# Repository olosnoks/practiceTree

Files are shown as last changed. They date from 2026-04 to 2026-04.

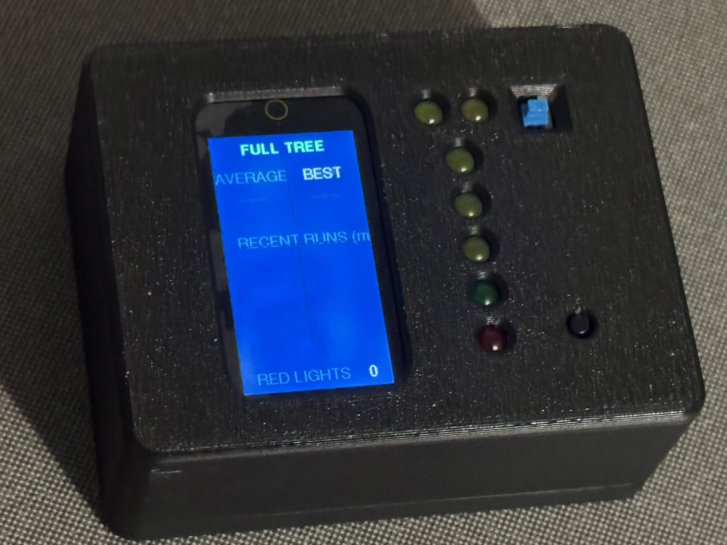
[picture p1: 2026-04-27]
hardware/3d/3d_printed_enclosure.jpg

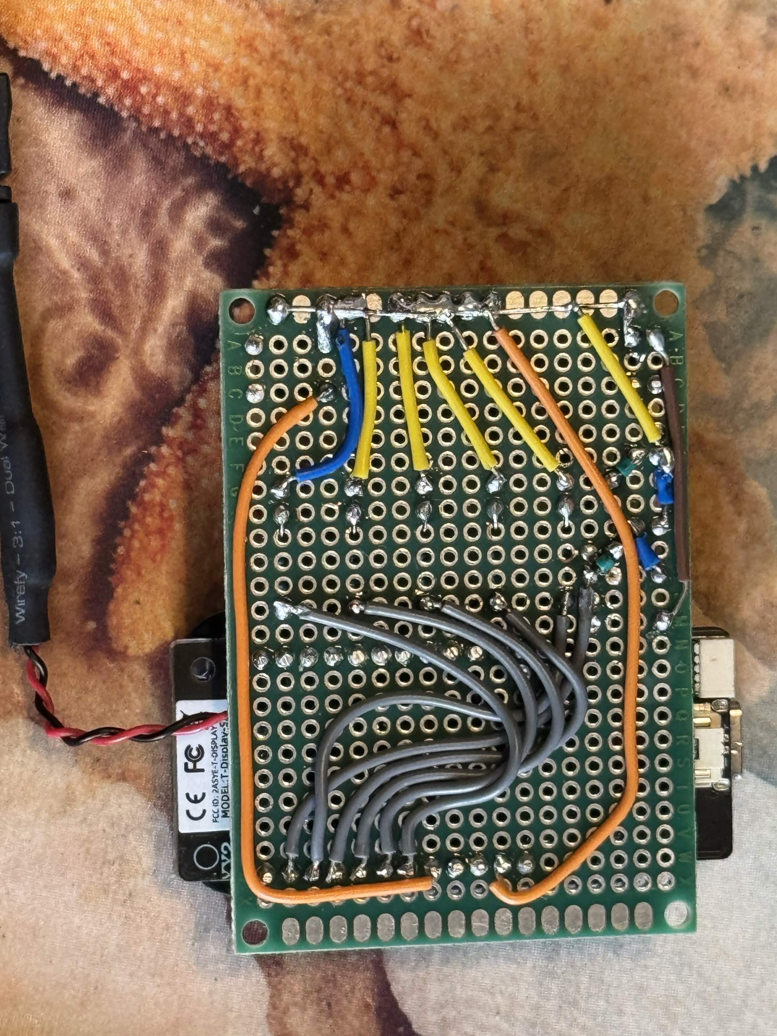
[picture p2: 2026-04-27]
hardware/3d/board_assembly_back.jpg

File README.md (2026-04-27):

# 🚦 Practice Tree — Reaction Timer for T-Display S3

A drag racing Christmas tree reaction timer built on the **LILYGO T-Display S3**, using an external LED tree and a single push button. Simulates a full NHRA-style countdown sequence and measures your reaction time to the nearest millisecond.

---

## ✨ Features

- 🌲 **Full Tree mode** — sequential yellow lights, 500ms between each
- ⚡ **Pro Tree mode** — sequential yellow lights, 100ms between each (triple-tap to switch)
- 🎲 **Random stage delay** — 1–7 second random hold after staging before the tree drops
- ⏱️ **Reaction time measurement** — millisecond-accurate, displayed in `.XXX` second format
- 🏆 **Personal best tracking** — best RT persists across all runs in the session, highlighted in blue
- 📊 **Rolling history** — last 12 reaction times displayed in a 2×6 grid
- 🔴 **Red light detection** — releasing before green increments the red light counter
- 💡 **Pre-stage debounce** — button must be held 500ms before staging LED fires (prevents accidental triggers)
- 🖥️ **Sprite-buffered display** — flicker-free rendering via LGFX double-buffering

---

## 🛠️ Bill of Materials

### Electronics

| Qty | Component | Specs | Notes |
|-----|---|---|---|
| 1 | LILYGO T-Display S3 | ESP32-S3, 1.9" ST7789 LCD | Main controller with integrated display |
| 1 | Perfboard | 5×7cm | LED tree assembly |
| 7 | Resistors | 680Ω, 1/4W | Current limiting — one per LED |
| 5 | Yellow LEDs | 5mm | Stage + tree countdown sequence |
| 1 | Green LED | 5mm | Go light |
| 1 | Red LED | 5mm | Red light / foul indicator |
| 1 | Push button | Momentary SPST | Trigger, wired to GPIO13 |
| 1 | Power switch | DPDT latching (6-pin) | Reset bypass for hard power-off |
| 1 | LiPo battery | 3.7V 2000mAh with JST connector | Portable power source |

### Hardware

| Qty | Size | Purpose |
|-----|---|---|
| 4 | 2mm × 8mm machine screws | Perfboard / component mounting |
| 4 | 2mm × 12mm machine screws | Enclosure assembly |

---

## 🔌 Wiring

### Pin Map

| GPIO | Connected To | Notes |
|---|---|---|
| `1`  | Stage LED + 680Ω resistor | Staging indicator |
| `2`  | Yellow 1 LED + 680Ω resistor | First yellow |
| `3`  | Yellow 2 LED + 680Ω resistor | Second yellow |
| `10` | Yellow 3 LED + 680Ω resistor | Third yellow |
| `11` | Green LED + 680Ω resistor | Go light |
| `12` | Red LED + 680Ω resistor | Red light / foul |
| `13` | Push button (to GND) | `INPUT_PULLUP` — reads LOW when pressed |
| `15` | Display power enable | Driven `HIGH` on boot to power the display |

### Button Wiring

The button uses the ESP32's internal pull-up — no external resistor needed:

```
GPIO 13 ───────────── Button ───────────── GND
              (INPUT_PULLUP)
```

### LED Wiring (per LED)

```
GPIO ──── [680Ω] ──── LED (+) ──── GND
```

### Power Switch — Reset Bypass

The DPDT latching switch forces an off state by shorting the RST signal pad on the reset button to GND:

```
RST signal pad ───── [Switch] ───── GND
```

When latched closed, the RST line is held LOW and the board stays in reset (off). Open the switch and the board boots normally.

**To wire:**
1. Solder a wire to the RST signal pad on the T-Display S3 reset button
2. Solder a wire to any GND pad or pin
3. Run both to your DPDT latching switch

### Schematic Overview

```
T-Display S3
┌────────────────┐
│ GPIO 1  ───────┼── 680Ω ── [STAGE  LED] ── GND
│ GPIO 2  ───────┼── 680Ω ── [YELLOW 1  ] ── GND
│ GPIO 3  ───────┼── 680Ω ── [YELLOW 2  ] ── GND
│ GPIO 10 ───────┼── 680Ω ── [YELLOW 3  ] ── GND
│ GPIO 11 ───────┼── 680Ω ── [GREEN  LED] ── GND
│ GPIO 12 ───────┼── 680Ω ── [RED    LED] ── GND
│ GPIO 13 ───────┼──────────── [BTN] ──── GND
│ GPIO 15 ───────┼── Display power enable
│ BAT+    ───────┼── LiPo (+) 3.7V JST
│ GND     ───────┼── LiPo (-)
│ RST Pad ───────┼── [Power Switch] ──── GND
└────────────────┘
```

---

## 🖥️ Display Screens

### Idle / History Screen

```
┌─────────────────────┐
│      FULL TREE      │  ← header (switches to PRO TREE)
├──────────┬──────────┤
│ AVERAGE  │  BEST    │
│  .412    │  .308    │  ← .XXX format; best in blue
├──────────┴──────────┤
│  RECENT RUNS (ms)   │
│  .412  │  .389      │
│  .455  │  .308      │  ← 2×6 grid, 12 entries max
│  ...   │  ...       │  ← best time highlighted in blue
├─────────────────────┤
│ RED LIGHTS        2 │  ← pinned to bottom
└─────────────────────┘
```

### Staging Screen

```
┌─────────────────────┐
│      FULL TREE      │
│                     │
│      STAGING        │
│  Hold the button... │
└─────────────────────┘
```

### Result Screen — Good Run

```
┌─────────────────────┐
│   REACTION TIME     │
│                     │
│       .412          │
│                     │
│   press for history │
└─────────────────────┘
```

### Result Screen — Red Light

```
┌─────────────────────┐
│                     │
│        RED          │
│       LIGHT         │
│   Press to reset    │
└─────────────────────┘
```

---

## 🕹️ Usage

### Basic Run

1. **Hold** the button — after 500ms the **stage LED** lights up
2. **Keep holding** — after a random 1–7s delay the yellow sequence fires
3. **Release** as fast as possible when the **green light** comes on
4. Your reaction time is displayed in `.XXX` format
5. **Press** again to return to the history screen

### Red Light

- Releasing **before green** fires the red LED and increments the counter
- Press the button to reset to idle

### Mode Switching — Triple Tap

Tap the button **3 times** quickly (each tap < 500ms hold, all 3 within a 1500ms window) to toggle between Full Tree and Pro Tree.

| Mode | Yellow Behavior | Timing |
|---|---|---|
| **Full Tree**| 500ms per step |
| **Pro Tree** | 100ms to green |

The active mode is shown in the header on every screen.

---

## 🛠️ Build & Flash

### Project Structure

```
practiceTree/
├── platformio.ini
├── src/
│   ├── main.cpp
│   └── LGFX_TDisplayS3.h
├── .gitignore
└── .gitattributes
```

### platformio.ini

```ini
[env:esp32s3]
platform      = espressif32
board         = esp32-s3-devkitc-1
framework     = arduino
monitor_speed = 115200
upload_speed  = 921600
lib_deps      =
    lovyanGFX
build_flags   =
    -D LGFX_USE_V1
```

### Arduino IDE

1. Install **ESP32 board package** via Boards Manager
2. Install **LovyanGFX** via Library Manager
3. Select board: **LILYGO T-Display-S3**
4. Copy both `src/main.cpp` and `src/LGFX_TDisplayS3.h` into the same sketch folder
5. Upload

---

## ⚙️ Configurable Constants

All tunable values are at the top of `src/main.cpp`:

| Constant | Default | Description |
|---|---|---|
| `PRE_STAGE_MS` | `500` | Hold time before staging LED fires (ms) |
| `STAGE_DELAY_MS` | `1000–7000` | Randomized delay before tree drops (ms) |
| `STEP_DELAY_MS` | `500` / `100` | Full tree step delay / Pro tree delay to green (ms) |
| `TAP_WINDOW_MS` | `1500` | Time window for triple-tap mode switch (ms) |
| `HISTORY_SIZE` | `12` | Number of previous runs stored and displayed |

---

## 📐 State Machine

```
         [hold 500ms]           [random 1–7s]
  IDLE ──────────────▶ PRE_STAGE ────────────▶ STAGING
   ▲                      │                      │
   │                 [release]             [delay elapsed]
   │                 (tap counted)               │
   │                      ▼              ┌───────┴────────┐
   │                    IDLE         Full Tree        Pro Tree
   │                                    │                │
   │                                  Y1_ON         PRO_YELLOW
   │                                    │ 500ms      (all 3 on)
   │                                  Y2_ON              │ 100ms
   │                                    │ 500ms           │
   │                                  Y3_ON               │
   │                                    │ 500ms           │
   │                                    └────────┬────────┘
   │                                             ▼
   │                                       GREEN_ON_HELD
   │                                             │
   │                    [release before green]   │   [release after green]
   │                             │               │
   │                          RED_END        GREEN_END
   │                             │               │
   └──────────[press]────────────┴───────────────┘
```

---

## 📄 License

MIT — do whatever you want with it. Build one for your buddy's Christmas present.

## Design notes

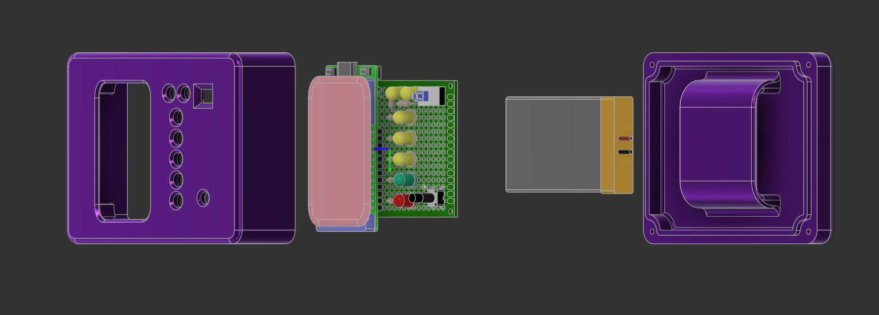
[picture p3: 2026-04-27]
hardware/3d/cad_render.png

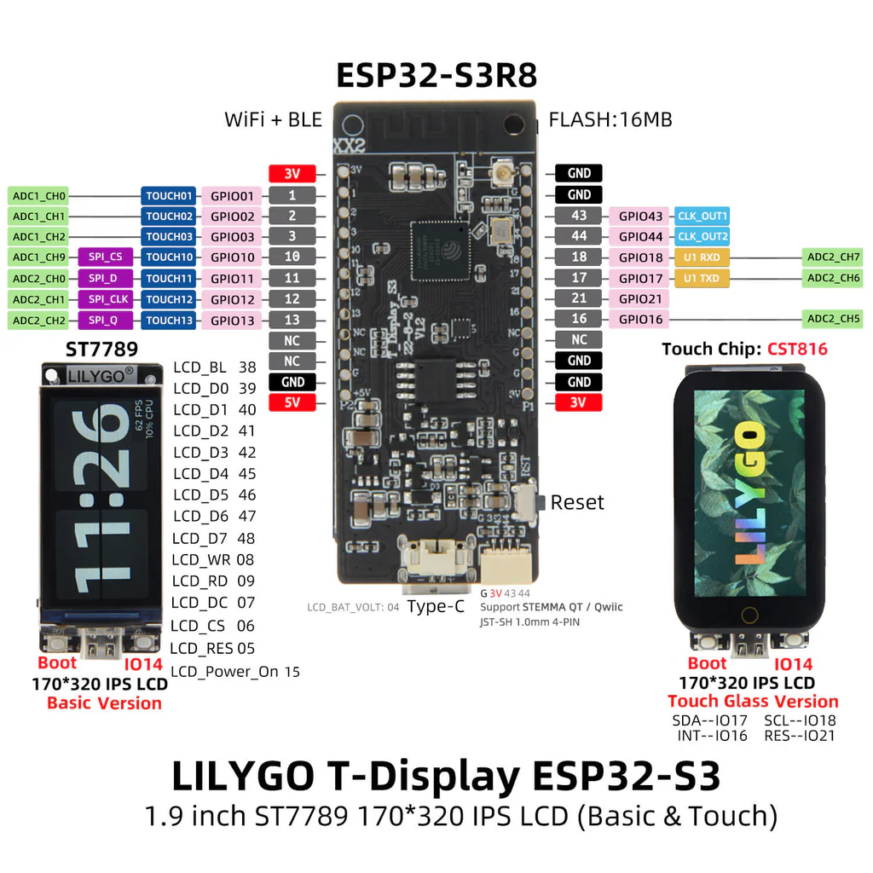
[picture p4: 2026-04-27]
hardware/T-DISPLAY-S3-Touch_1024x1024.webp

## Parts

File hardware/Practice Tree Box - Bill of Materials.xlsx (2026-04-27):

# | Item | Description / Notes | Category | Qty | Unit | Amazon Link
1 | LilyGo T-Display S3 | ESP32-S3 dev board with 1.9" TFT display, USB-C, onboard LiPo charging IC, JST battery connector | Microcontroller | 1 | pcs | LilyGo T-Display S3 (https://www.amazon.com/dp/B0BF542H39)
2 | 3.7V 2000mAh LiPo Battery | With JST-PH 2.0 connector, rechargeable via onboard LilyGo charging IC | Power | 1 | pcs | EEMB 3.7V 2000mAh LiPo JST (https://www.amazon.com/dp/B09DPP44GM)
3 | 6-Pin DPDT Latching Tactile Switch | Push-on/push-off PCB mount switch, 3 legs per side; wired to RST pad and GND on LilyGo to force hardware OFF state while allowing charging | Power | 1 | pcs | Antrader 30pc 6-Pin DPDT Latching Switch (https://www.amazon.com/dp/B07QVX1CKZ)
4 | Yellow 5mm LED | Used for tree light sequence (staging lights) | LEDs | 5 | pcs | DiCUNO 450pc 5mm LED Assorted Kit (https://www.amazon.com/dp/B073QMYKDM)
5 | Red 5mm LED | Used for tree light sequence (Red-Light indicator) | LEDs | 1 | pcs | DiCUNO 450pc 5mm LED Assorted Kit
6 | Green 5mm LED | Used for tree light sequence (GO light) | LEDs | 1 | pcs | DiCUNO 450pc 5mm LED Assorted Kit
7 | 680 Ohm 1/4W Resistor | Current limiting resistors for all 7 LEDs (5x Yellow + 1x Red + 1x Green), one per LED | Passives | 7 | pcs | 100pc 680 Ohm 1/4W Carbon Film Resistors (https://www.amazon.com/dp/B0CL9LX4R3)
8 | 5x7cm Perfboard | Prototype PCB for soldering all components | Mechanical | 1 | pcs | HiLetgo 20pc 5x7cm Perfboard (https://www.amazon.com/dp/B00FXHXT80)
9 | M2x8mm Screw | For mounting PCB to 3D printed Front | Hardware | 4 | pcs | 1260pc M2 Screw Assortment Kit (4-20mm) (https://www.amazon.com/dp/B0FG2CC91J)
10 | M2x12mm Screw | For mounting 3D printed Back to Front | Hardware | 4 | pcs | 1260pc M2 Screw Assortment Kit (4-20mm)
11 | Hookup Wire (assorted) | Thin stranded wire for point-to-point wiring on perfboard and switch connections | Wiring | 1 | roll | TUOFENG 22AWG Hookup Wire 6 Colors (https://www.amazon.com/dp/B07TX6BX47)
13 | 6x6x12mm Momentary Tactile Pushbutton | 4-pin PCB DIP through-hole, normally open, tall stem; used to trigger the practice tree light sequence | Switches | 1 | pcs | uxcell 6x6x12mm 4-Pin DIP Tactile Switch 10pcs (https://www.amazon.com/dp/B07JLV6WSF)

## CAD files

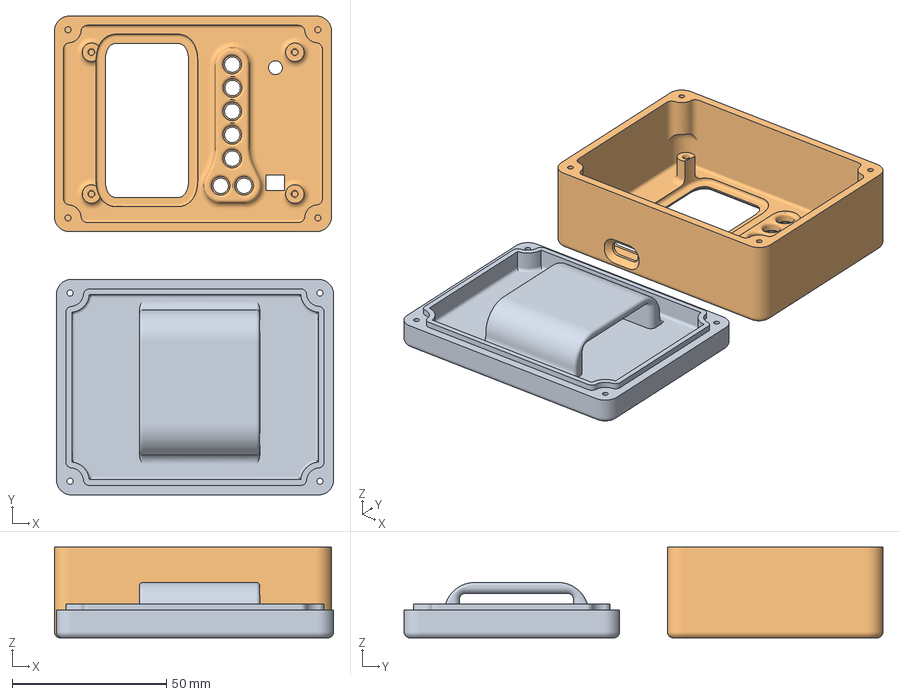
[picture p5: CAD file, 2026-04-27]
hardware/3d/DIY_Practice_Tree.3mf
90.7 x 155.4 x 29.5 mm
back
front

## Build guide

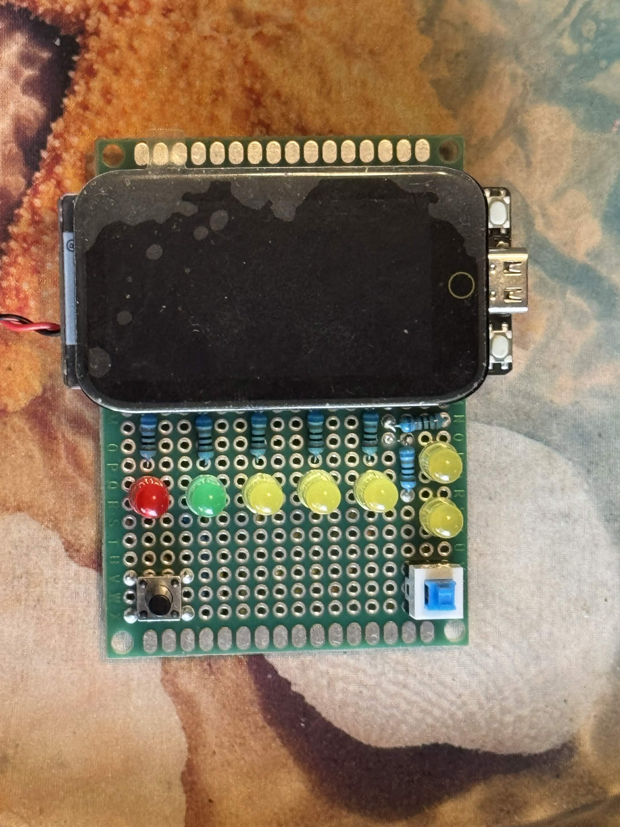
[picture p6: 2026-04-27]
hardware/3d/board_assembly.jpg

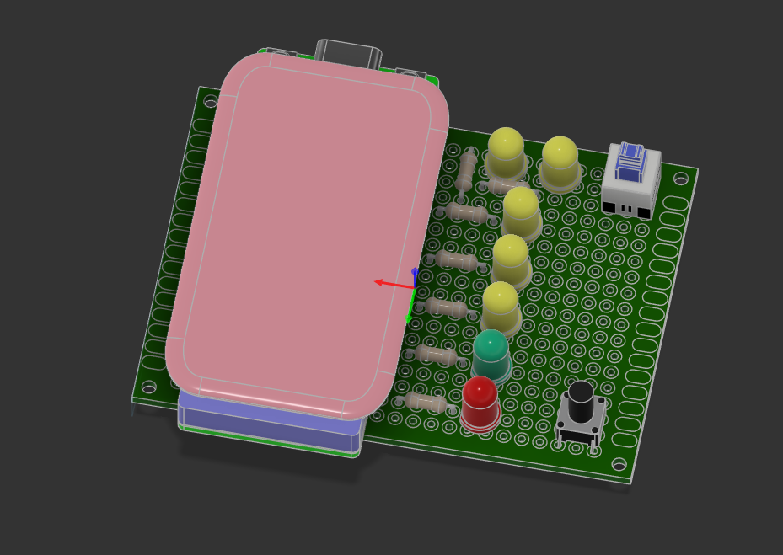
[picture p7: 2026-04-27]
hardware/3d/board_assembly.png

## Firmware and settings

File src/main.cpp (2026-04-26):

#include <Arduino.h>
#define LGFX_USE_V1
#include "LGFX_TDisplayS3.h"


// ── Display ───────────────────────────────────────────────────────
static LGFX_TDisplayS3 lcd;
static LGFX_Sprite      spr(&lcd);
constexpr int DISPLAY_POWER_PIN = 15;
int  redLightCount = 0;
bool proTreeMode   = false;


// Tap detection for mode switching
int           tapCount    = 0;
unsigned long lastTapTime = 0;
const unsigned long TAP_WINDOW_MS    = 1500;
const unsigned long PRE_STAGE_MS     = 500;


unsigned long tachStartTime = 0;
bool tachAnimating = false;


// =================================================================
// GAME CODE
// =================================================================


const int PIN_STAGE = 1;
const int PIN_Y1    = 2;
const int PIN_Y2    = 3;
const int PIN_Y3    = 10;
const int PIN_GREEN = 11;
const int PIN_RED   = 12;
const int PIN_BTN   = 13;


enum TreeState {
  IDLE,
  PRE_STAGE,
  STAGING,
  Y1_ON,
  Y2_ON,
  Y3_ON,
  PRO_YELLOW,
  GREEN_ON_HELD,
  RED_END,
  GREEN_END
};


TreeState state = IDLE;


unsigned long stateStartTime = 0;
unsigned long STAGE_DELAY_MS = 2000;
unsigned long STEP_DELAY_MS  = 500;


unsigned long greenOnTimeMs  = 0;
unsigned long lastReactionMs = 0;
unsigned long bestReactionMs = 0;   // best (lowest) reaction time ever recorded


const int HISTORY_SIZE = 12;
unsigned long reactionHistory[HISTORY_SIZE] = {0};
int historyCount = 0;


bool buttonPressed() {
  return digitalRead(PIN_BTN) == LOW;
}


void allOff() {
  digitalWrite(PIN_STAGE, LOW);
  digitalWrite(PIN_Y1, LOW);
  digitalWrite(PIN_Y2, LOW);
  digitalWrite(PIN_Y3, LOW);
  digitalWrite(PIN_GREEN, LOW);
  digitalWrite(PIN_RED, LOW);
}


void addReactionToHistory(unsigned long rt) {
  for (int i = HISTORY_SIZE - 1; i > 0; --i) {
    reactionHistory[i] = reactionHistory[i - 1];
  }
  reactionHistory[0] = rt;
  if (historyCount < HISTORY_SIZE) historyCount++;

  if (bestReactionMs == 0 || rt < bestReactionMs) {
    bestReactionMs = rt;
  }
}


float averageReaction() {
  if (historyCount == 0) return 0.0f;
  unsigned long sum = 0;
  for (int i = 0; i < historyCount; ++i) sum += reactionHistory[i];
  return (float)sum / (float)historyCount;
}



// Format reaction time as ".XXX" (sub-second) or "1.XXX" (1s+)
void formatRT(char* buf, int bufSize, unsigned long ms) {
  snprintf(buf, bufSize, "%.3f", ms / 1000.0f);
  if (buf[0] == '0') memmove(buf, buf + 1, strlen(buf)); // strip leading zero
}

// =================================================================
// DISPLAY LAYER
// =================================================================


void drawHeader() {
  const int W = spr.width();
  spr.fillRect(0, 0, W, 36, 0x1A1A1A);
  spr.setTextDatum(MC_DATUM);
  spr.setFont(&fonts::FreeSansBold9pt7b);
  spr.setTextSize(1);
  spr.setTextColor(0x4CAF50);
  spr.drawString(proTreeMode ? "PRO TREE" : "FULL TREE", W / 2, 18);
}


void drawDisplay() {
  const int W = spr.width();
  const int H = spr.height();

  spr.fillSprite(0x0A0A0A);
  char buf[16];


  if (state == GREEN_END) {

    drawHeader();
    spr.setTextDatum(MC_DATUM);
    spr.setFont(&fonts::FreeSans9pt7b);
    spr.setTextColor(0x666666);
    spr.drawString("REACTION TIME", W / 2, 80);

    spr.setFont(&fonts::FreeSansBold9pt7b);
    spr.setTextSize(2);
    spr.setTextColor(TFT_WHITE);
    formatRT(buf, sizeof(buf), lastReactionMs);
    spr.drawString(buf, W / 2, 120);


    spr.setTextColor(0x333333);
    spr.drawString("press for history", W / 2, H - 20);


  } else if (state == IDLE || state == PRE_STAGE) {

    drawHeader();

    // ── Stats row: AVG (left) + BEST (right) ──────────────────────
    const int colL = W / 4;
    const int colR = (W * 3) / 4;

    const int statsLabelY = 54;
    const int statsValueY = 82;

    spr.setFont(&fonts::FreeSans9pt7b);
    spr.setTextSize(1);
    spr.setTextDatum(MC_DATUM);

    spr.setTextColor(0x555555);
    spr.drawString("AVERAGE", colL, statsLabelY);
    spr.setTextColor(TFT_WHITE);
    spr.drawString("BEST", colR, statsLabelY);

    spr.setFont(&fonts::FreeSansBold9pt7b);
    spr.setTextSize(2);

    if (historyCount > 0) {
      spr.setTextColor(TFT_WHITE);
      formatRT(buf, sizeof(buf), (unsigned long)averageReaction());
    } else {
      spr.setTextColor(0x333333);
      snprintf(buf, sizeof(buf), "---");
    }
    spr.drawString(buf, colL, statsValueY);

    if (bestReactionMs > 0) {
      spr.setTextColor(TFT_WHITE);
      formatRT(buf, sizeof(buf), bestReactionMs);
    } else {
      spr.setTextColor(0x333333);
      snprintf(buf, sizeof(buf), "---");
    }
    spr.drawString(buf, colR, statsValueY);

    spr.setTextSize(1);
    spr.setFont(&fonts::FreeSans9pt7b);

    spr.drawFastVLine(W / 2, 48, 68, 0x222222);

    // ── Footer pinned to bottom ────────────────────────────────────
    const int footerLineY = H - 34;
    const int footerTextY = H - 24;

    spr.drawFastHLine(16, footerLineY, W - 32, 0x2A2A2A);
    spr.setTextDatum(TL_DATUM);
    spr.setTextColor(0x555555);
    spr.setFont(&fonts::FreeSans9pt7b);
    spr.drawString("RED LIGHTS", 16, footerTextY);
    spr.setTextDatum(TR_DATUM);
    spr.setTextColor(TFT_WHITE);
    snprintf(buf, sizeof(buf), "%d", redLightCount);
    spr.drawString(buf, W - 16, footerTextY);

    // ── Recent runs section (2x5 grid) ────────────────────────────
    const int recentTitleY = 128;
    const int recentLineY  = 140;
    const int rowY0        = 154;
    const int rowH         = 18;

    spr.drawFastHLine(16, recentTitleY - 8, W - 32, 0x2A2A2A);
    spr.setTextColor(0x555555);
    spr.setTextDatum(TL_DATUM);
    spr.drawString("RECENT RUNS (ms)", 16, recentTitleY);
    spr.drawFastHLine(16, recentLineY, W - 32, 0x222222);

    int count = min(historyCount, HISTORY_SIZE);
    for (int i = 0; i < count; i++) {
      int  row     = i / 2;
      bool leftCol = (i % 2 == 0);
      int x = leftCol ? colL : colR;
      int y = rowY0 + row * rowH;

      formatRT(buf, sizeof(buf), reactionHistory[i]);
      spr.setTextColor(reactionHistory[i] == bestReactionMs ? (uint32_t)0x6699CC : (uint32_t)TFT_WHITE);
      spr.setTextDatum(MC_DATUM);
      spr.drawString(buf, x, y);
    }

    int historyHeight = footerLineY - rowY0 - 4;
    if (historyHeight > 0) {
      spr.drawFastVLine(W / 2, recentLineY, historyHeight, 0x222222);
    }


  } else if (state == RED_END) {

    spr.setTextDatum(MC_DATUM);
    spr.setTextColor(TFT_RED);
    spr.setTextSize(2);
    spr.setFont(&fonts::FreeSansBold9pt7b);
    spr.drawString("RED", W / 2, H / 2 - 24);
    spr.drawString("LIGHT", W / 2, H / 2 + 4);
    spr.setTextSize(1);
    spr.setTextColor(0x555555);
    spr.setFont(&fonts::FreeSans9pt7b);
    spr.drawString("Press to reset", W / 2, H / 2 + 46);


  } else {

    // STAGING, Y1_ON, Y2_ON, Y3_ON, PRO_YELLOW, GREEN_ON_HELD
    drawHeader();
    spr.setTextDatum(MC_DATUM);
    spr.setTextColor(0xFFCC00);
    spr.setTextSize(2);
    spr.setFont(&fonts::FreeSansBold9pt7b);
    spr.drawString("STAGING", W / 2, H / 2 - 14);
    spr.setTextSize(1);
    spr.setTextColor(0x444444);
    spr.setFont(&fonts::FreeSans9pt7b);
    spr.drawString("Hold the button...", W / 2, H / 2 + 22);

  }

  spr.pushSprite(0, 0);
}


// =================================================================
// SETUP & LOOP
// =================================================================


void setup() {
  pinMode(DISPLAY_POWER_PIN, OUTPUT);
  digitalWrite(DISPLAY_POWER_PIN, HIGH);
  delay(10);

  lcd.init();
  lcd.setRotation(2);
  lcd.setBrightness(200);
  spr.setColorDepth(16);
  spr.createSprite(lcd.width(), lcd.height());

  Serial.begin(115200);
  delay(500);

  pinMode(PIN_STAGE, OUTPUT);
  pinMode(PIN_Y1,    OUTPUT);
  pinMode(PIN_Y2,    OUTPUT);
  pinMode(PIN_Y3,    OUTPUT);
  pinMode(PIN_GREEN, OUTPUT);
  pinMode(PIN_RED,   OUTPUT);
  pinMode(PIN_BTN,   INPUT_PULLUP);

  allOff();
  drawDisplay();

  Serial.println("=== Drag tree with reaction time ===");
  Serial.println("Release BEFORE green -> red only.");
  Serial.println("Release AFTER green -> green only + reaction time.");
}


void loop() {
  unsigned long now = millis();
  bool pressed = buttonPressed();

  TreeState prevState = state;

  switch (state) {

    case IDLE:
      allOff();
      if (pressed) {
        Serial.println("[IDLE] -> PRE_STAGE");
        stateStartTime = now;
        state = PRE_STAGE;
      }
      break;

    case PRE_STAGE:
      if (!pressed) {
        Serial.println("[PRE_STAGE] Released quickly -> IDLE (tap)");
        state = IDLE;
        break;
      }
      if (now - stateStartTime >= PRE_STAGE_MS) {
        Serial.println("[PRE_STAGE] 500ms held -> STAGING");
        STAGE_DELAY_MS = random(1000, 7001);
        Serial.print("[PRE_STAGE] Stage delay = ");
        Serial.print(STAGE_DELAY_MS);
        Serial.println(" ms");
        digitalWrite(PIN_STAGE, HIGH);
        stateStartTime = now;
        state = STAGING;
      }
      break;

    case STAGING:
      digitalWrite(PIN_STAGE, HIGH);
      if (!pressed) {
        Serial.println("[STAGING] Released early -> IDLE");
        state = IDLE;
        break;
      }
      if (now - stateStartTime >= STAGE_DELAY_MS) {
        Serial.println("[STAGING] delay elapsed -> Y1_ON");
        digitalWrite(PIN_Y1, HIGH);
        stateStartTime = now;
        state = Y1_ON;
      }
      break;

    case PRO_YELLOW:
      digitalWrite(PIN_STAGE, HIGH);
      digitalWrite(PIN_Y1, HIGH);
      digitalWrite(PIN_Y2, HIGH);
      digitalWrite(PIN_Y3, HIGH);
      if (!pressed) {
        Serial.println("[PRO_YELLOW] Released early -> RED_END");
        allOff();
        digitalWrite(PIN_RED, HIGH);
        state = RED_END;
        break;
      }
      if (now - stateStartTime >= STEP_DELAY_MS) {
        Serial.println("[PRO_YELLOW] 400ms elapsed -> GREEN_ON_HELD");
        digitalWrite(PIN_GREEN, HIGH);
        greenOnTimeMs = now;
        state = GREEN_ON_HELD;
      }
      break;

    case Y1_ON:
      digitalWrite(PIN_STAGE, HIGH);
      digitalWrite(PIN_Y1, HIGH);
      if (!pressed) {
        Serial.println("[Y1_ON] Released -> RED_END");
        allOff();
        digitalWrite(PIN_RED, HIGH);
        state = RED_END;
        break;
      }
      if (now - stateStartTime >= STEP_DELAY_MS) {
        Serial.println("[Y1_ON] elapsed -> Y2_ON");
        digitalWrite(PIN_Y2, HIGH);
        stateStartTime = now;
        state = Y2_ON;
      }
      break;

    case Y2_ON:
      digitalWrite(PIN_STAGE, HIGH);
      digitalWrite(PIN_Y1, HIGH);
      digitalWrite(PIN_Y2, HIGH);
      if (!pressed) {
        Serial.println("[Y2_ON] Released -> RED_END");
        allOff();
        digitalWrite(PIN_RED, HIGH);
        state = RED_END;
        break;
      }
      if (now - stateStartTime >= STEP_DELAY_MS) {
        Serial.println("[Y2_ON] elapsed -> Y3_ON");
        digitalWrite(PIN_Y3, HIGH);
        stateStartTime = now;
        state = Y3_ON;
      }
      break;

    case Y3_ON:
      digitalWrite(PIN_STAGE, HIGH);
      digitalWrite(PIN_Y1, HIGH);
      digitalWrite(PIN_Y2, HIGH);
      digitalWrite(PIN_Y3, HIGH);
      if (!pressed) {
        Serial.println("[Y3_ON] Released -> RED_END");
        allOff();
        digitalWrite(PIN_RED, HIGH);
        state = RED_END;
        break;
      }
      if (now - stateStartTime >= STEP_DELAY_MS) {
        Serial.println("[Y3_ON] elapsed -> GREEN_ON_HELD");
        digitalWrite(PIN_GREEN, HIGH);
        greenOnTimeMs = now;
        state = GREEN_ON_HELD;
      }
      break;

    case GREEN_ON_HELD:
      digitalWrite(PIN_STAGE, HIGH);
      digitalWrite(PIN_Y1,    HIGH);
      digitalWrite(PIN_Y2,    HIGH);
      digitalWrite(PIN_Y3,    HIGH);
      digitalWrite(PIN_GREEN, HIGH);
      if (!pressed) {
        unsigned long releaseTime = now;
        lastReactionMs = releaseTime - greenOnTimeMs;
        addReactionToHistory(lastReactionMs);
        Serial.print("[GREEN_ON_HELD] Good hit, reaction = ");
        Serial.print(lastReactionMs);
        Serial.print(" ms, avg = ");
        Serial.print(averageReaction());
        Serial.print(" ms, best = ");
        Serial.print(bestReactionMs);
        Serial.println(" ms");
        allOff();
        digitalWrite(PIN_GREEN, HIGH);
        state = GREEN_END;
      }
      break;

    case RED_END:
      if (pressed) {
        Serial.println("[RED_END] Reset -> IDLE");
        state = IDLE;
      }
      break;

    case GREEN_END:
      if (pressed) {
        Serial.println("[GREEN_END] Reset -> IDLE");
        state = IDLE;
      }
      break;
  }


  // ── State change hook (display layer only) ────────────────────────
  if (state != prevState) {

    if (prevState == PRE_STAGE && state == IDLE) {
      if (now - lastTapTime < TAP_WINDOW_MS) {
        tapCount++;
      } else {
        tapCount = 1;
      }
      lastTapTime = now;

      if (tapCount >= 3) {
        proTreeMode   = !proTreeMode;
        STEP_DELAY_MS = proTreeMode ? 100 : 500;
        tapCount      = 0;
        Serial.print("[MODE] Switched to ");
        Serial.println(proTreeMode ? "PRO TREE (400ms simultaneous)" : "FULL TREE (500ms sequence)");
      }
    }

    if (state == GREEN_END || state == RED_END) tapCount = 0;
    if (state == RED_END) redLightCount++;

    // Skip no-op redraw on IDLE -> PRE_STAGE (display is identical to IDLE)
    if (!(prevState == IDLE && state == PRE_STAGE)) {
      drawDisplay();
    }
  }

  delay(1);
}

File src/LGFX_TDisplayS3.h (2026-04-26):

#pragma once
#define LGFX_USE_V1
#include <LovyanGFX.hpp>

class LGFX_TDisplayS3 : public lgfx::LGFX_Device {
  lgfx::Bus_Parallel8 _bus_instance;
  lgfx::Panel_ST7789  _panel_instance;
  lgfx::Light_PWM     _light_instance;

public:
  LGFX_TDisplayS3(void) {
    // --- 8-bit parallel bus config ---
    {
      auto cfg = _bus_instance.config();
      cfg.port          = 0;
      cfg.freq_write    = 20000000;
      cfg.pin_wr        = 8;
      cfg.pin_rd        = 9;
      cfg.pin_rs        = 7;   // D/C
      cfg.pin_d0        = 39;
      cfg.pin_d1        = 40;
      cfg.pin_d2        = 41;
      cfg.pin_d3        = 42;
      cfg.pin_d4        = 45;
      cfg.pin_d5        = 46;
      cfg.pin_d6        = 47;
      cfg.pin_d7        = 48;
      _bus_instance.config(cfg);
      _panel_instance.setBus(&_bus_instance);
    }

    // --- Panel config ---
    {
      auto cfg = _panel_instance.config();
      cfg.pin_cs        = 6;
      cfg.pin_rst       = 5;
      cfg.pin_busy      = -1;
      cfg.panel_width   = 170;
      cfg.panel_height  = 320;
      cfg.offset_x      = 35;
      cfg.offset_y      = 0;
      cfg.offset_rotation = 0;
      cfg.dummy_read_pixel = 8;
      cfg.dummy_read_bits  = 1;
      cfg.readable      = false;
      cfg.invert        = true;   // T-Display-S3 requires color inversion
      cfg.rgb_order     = false;
      cfg.dlen_16bit    = false;
      cfg.bus_shared    = false;
      _panel_instance.config(cfg);
    }

    // --- Backlight config ---
    {
      auto cfg = _light_instance.config();
      cfg.pin_bl        = 38;
      cfg.invert        = false;
      cfg.freq          = 12000;
      cfg.pwm_channel   = 7;
      _light_instance.config(cfg);
      _panel_instance.setLight(&_light_instance);
    }

    setPanel(&_panel_instance);
  }
};

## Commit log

2026-04-26 Revise README for DragTree project details
    Updated project name and added detailed features, usage instructions, wiring information, build instructions, configurable constants, state machine diagram, and license information.
2026-04-27 Refactor README for clarity and structure
    Update README to improve formatting and organization of features, wiring, and assembly notes.
2026-04-27 3d stuff
    [DIY_Practice_Tree.3mf, Practice Tree Box - Bill of Materials.xlsx]
2026-04-27 Revise README for accuracy and clarity
    Updated README to reflect changes in features, bill of materials, wiring, and usage instructions.
